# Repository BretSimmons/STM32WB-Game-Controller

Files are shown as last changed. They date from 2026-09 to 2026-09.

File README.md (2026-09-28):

# STM32WB Game Controller

Custom microcontroller for running embedded games and other programming projects.

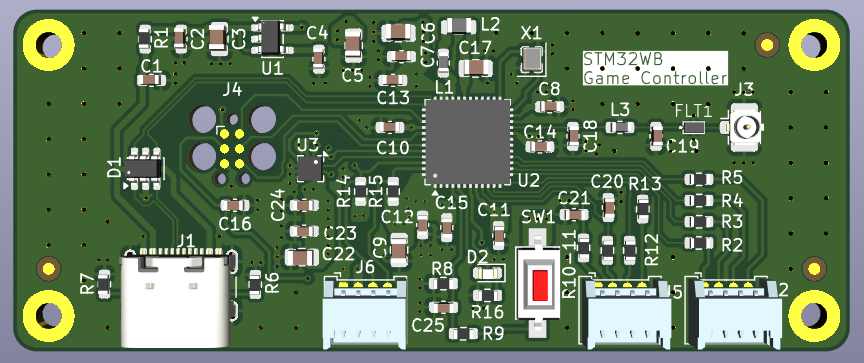
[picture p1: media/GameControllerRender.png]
Demo


**Functionality:**

My original idea for this board was to create a microcontroller to run an embedded pong game I wrote a few months ago [(here)](https://github.com/BretSimmons/Embedded-Pong). I ended up adding the requried perhipherals (I2C, ADC, and 4 GPIO pins), but also UART, and a connector for an RF antenna. I wanted to create a multi purpose microcontroller I can use in future projects, and gain experience impedence matching traces for high frequencies.

**How It Works:**

The board is powered by an USB-C header and runs through ESD protection and a step down voltage regulator to power the STM32WB55xx MCU. The MCU can be programmed via either the USB or a Tag Connect header. The MCU contains several internal clocks, and I additionally included an external crystal oscillator. The perhipherals can be configured via software, and routed out via the Molex headers on the board. 

**Future Updates:**

This project is a work in progress, and there are still a couple of changes I want to make before ordering the PCB. Once I have it ordered and assembled I will update this repo with a video demo.

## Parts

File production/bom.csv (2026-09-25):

Designator | Footprint | Quantity | Value | LCSC Part #
C1, C10, C11, C12, C13, C14, C15, C16, C2, C20, C21, C23, C24, C25, C4, C7, C8 | 0603 | 17 | 100n
C17, C22, C3, C5, C6, C9 | 0805 | 6 | 4u7
C18 | 0603 | 1 | 0p8
C19 | 0603 | 1 | 0p3
D1 | SOT-23-6 | 1 | USBLC6-2SC6
D2 | 0603 | 1 | LED
FLT1 | DLF162500LT-5028A1 | 1 | DLF162500LT-5028A1
J1 | USB_C_Receptacle_GCT_USB4105-xx-A_16P_TopMnt_Horizontal | 1 | USB_C_Receptacle_USB2.0_14P
J2, J5, J6 | Molex_PicoBlade_53048-0410_1x04_P1.25mm_Horizontal | 3 | Conn_01x04_Pin
J3 | U.FL_Hirose_U.FL-R-SMT-1_Vertical | 1 | Conn_Coaxial
L1 | 0603 | 1 | 10n
L2 | 0805 | 1 | 10u
L3 | 0603 | 1 | 2n7
R1 | 0603 | 1 | 0R
R10-11, R11, R14, R15, R6, R7, R8 | 0603 | 7 | 5k1
R12, R13, R16, R2, R3, R4, R5, R9 | 0603 | 8 | 220R
SW1 | SW_SPST_CK_RS282G05A3 | 1 | SW_Push
U1 | SOT-23-5 | 1 | SPX3819M5-L-3-3
U2 | QFN-48-1EP_7x7mm_P0.5mm_EP5.6x5.6mm | 1 | STM32WB55CEU6
U3 | LGA-12_2x2mm_P0.5mm | 1 | LIS2HH12
X1 | Crystal_SMD_2016-4Pin_2.0x1.6mm | 1 | 32MHz

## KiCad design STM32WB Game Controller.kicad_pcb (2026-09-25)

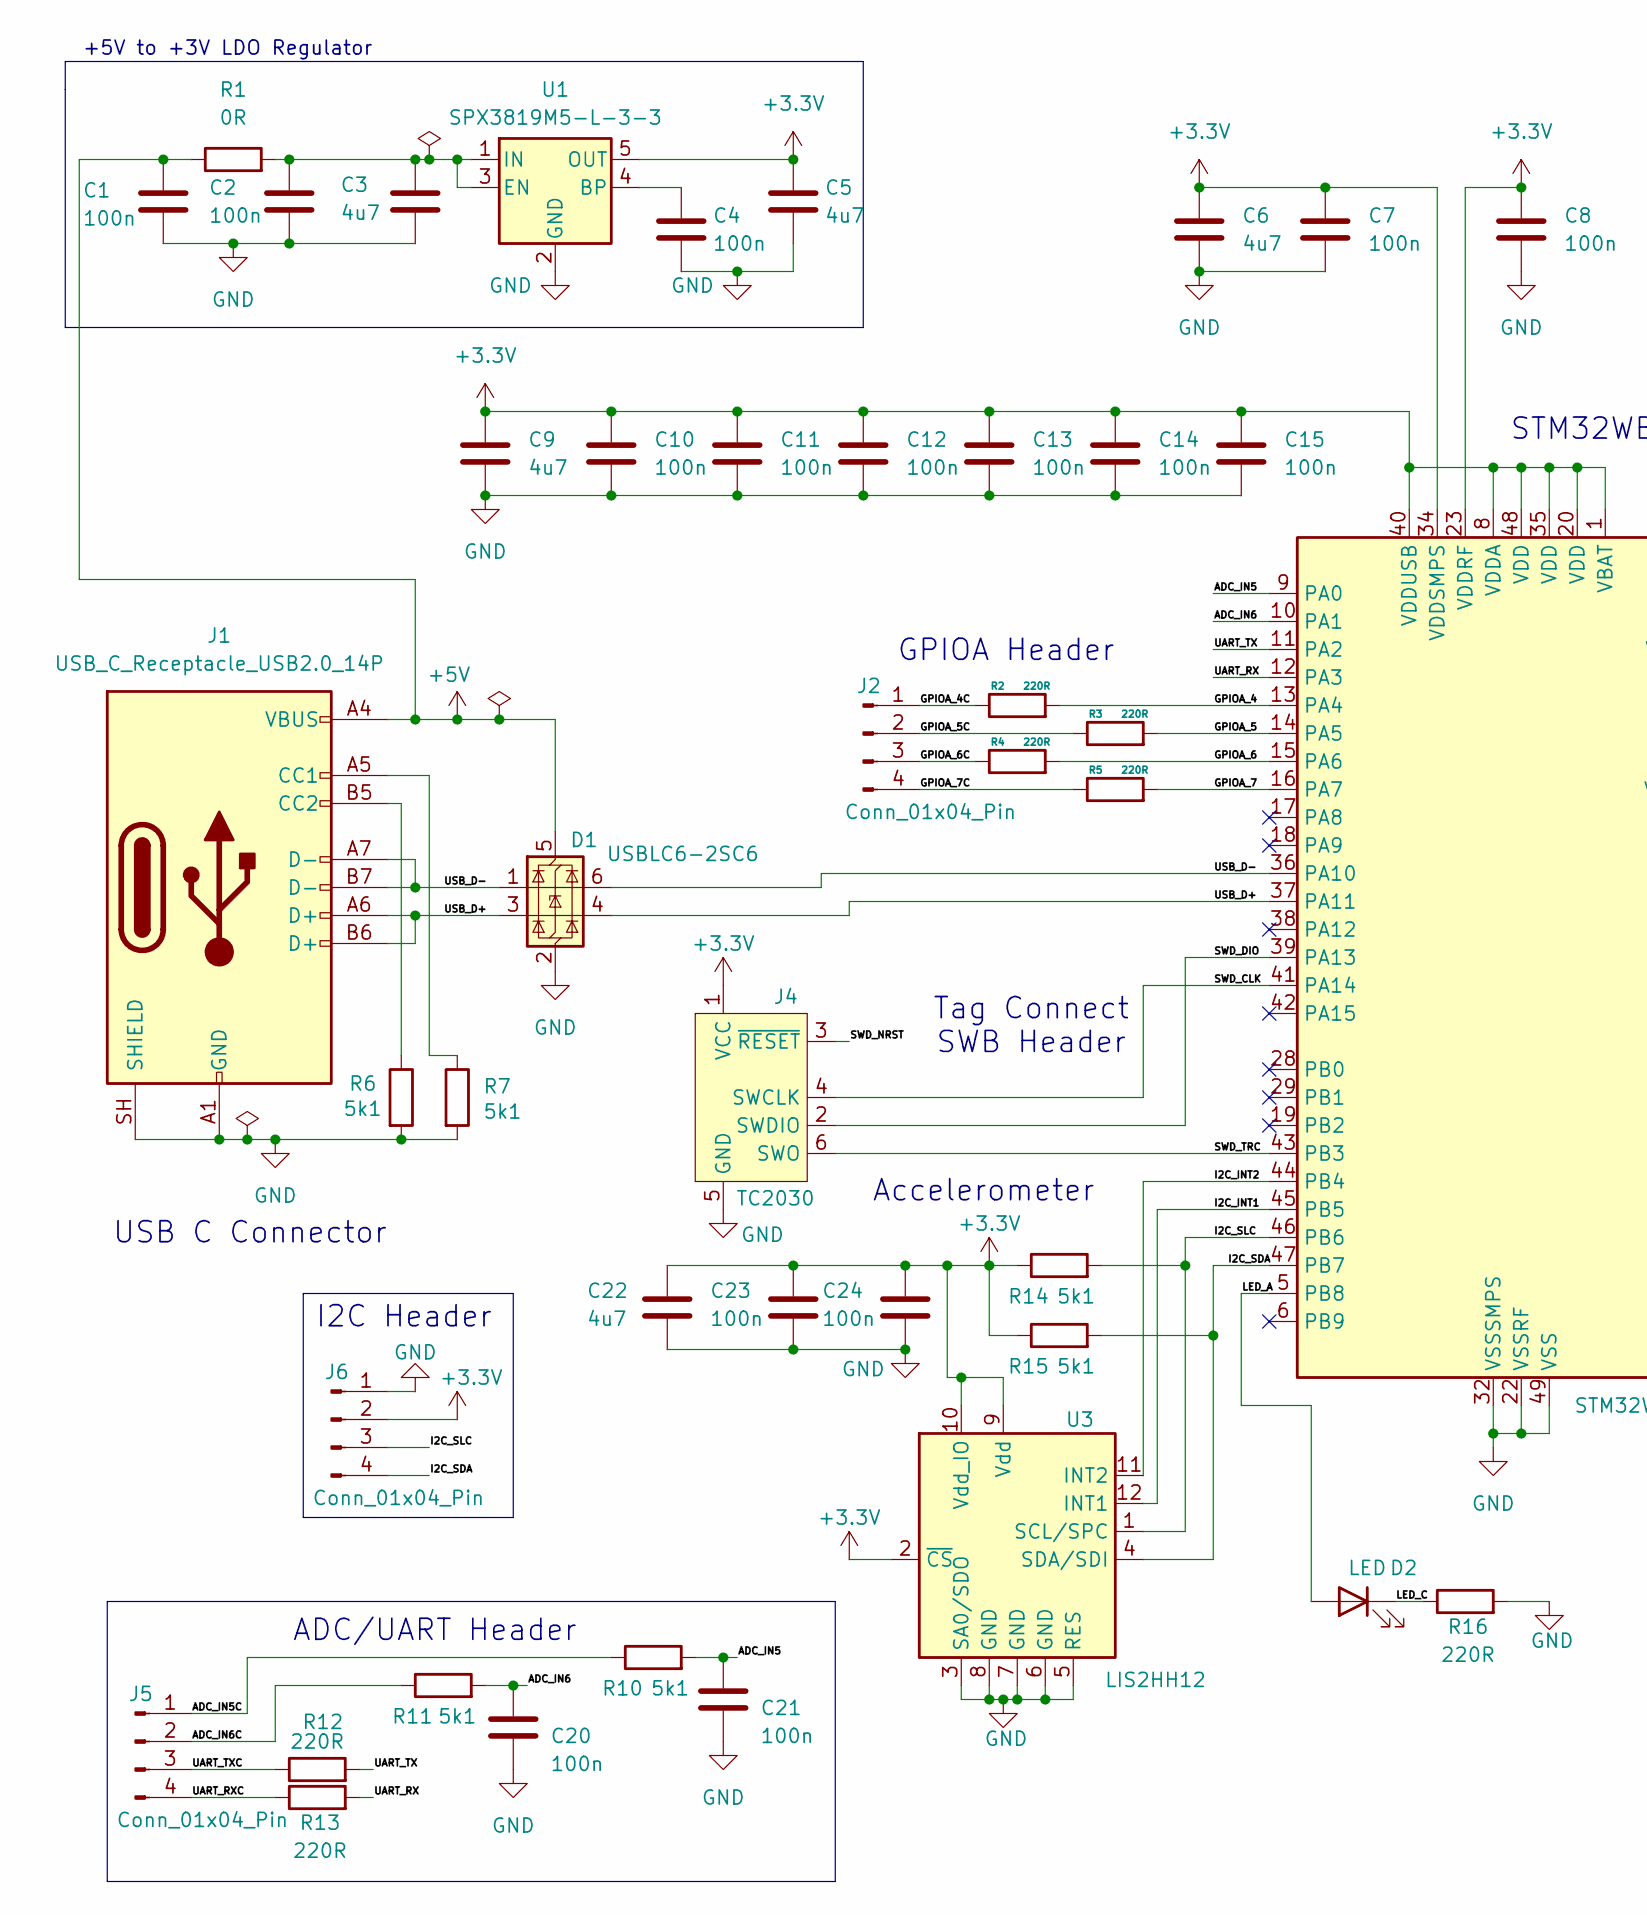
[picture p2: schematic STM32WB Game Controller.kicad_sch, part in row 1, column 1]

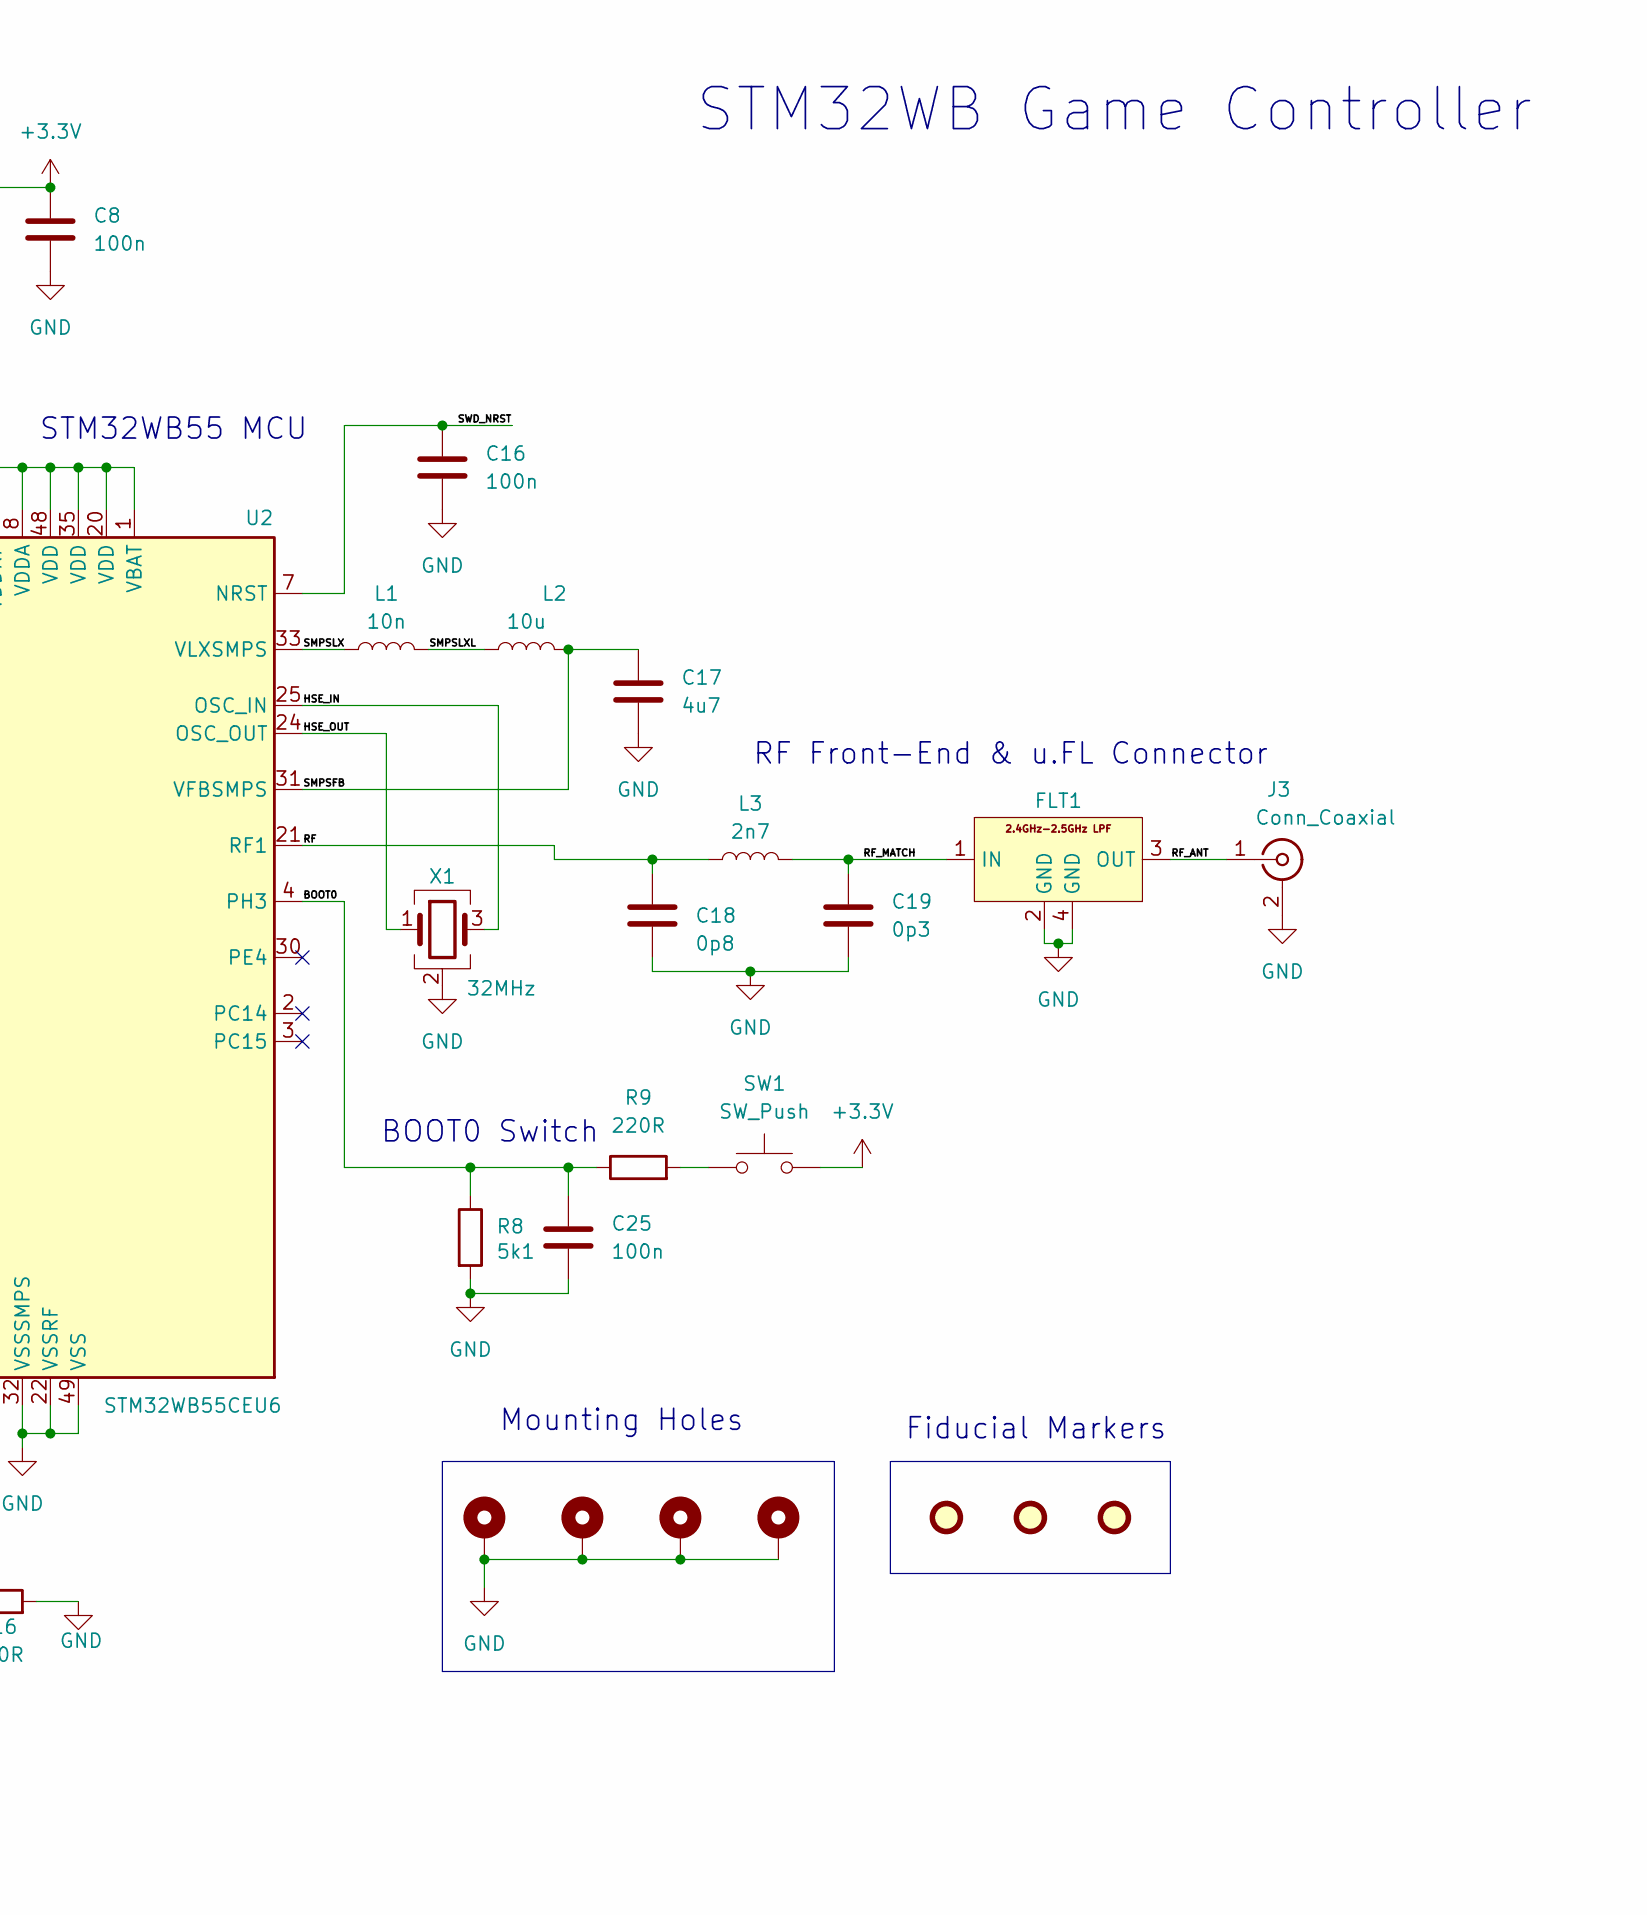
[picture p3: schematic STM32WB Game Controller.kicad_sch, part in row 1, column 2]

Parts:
C1, C2, C4, C7, C8, C10, C11, C12, C13, C14, C15, C16, C20, C21, C23, C24, C25: 100n; C_0603_1608Metric; Manufacturer Part Number CC0603JRX7R9BB104
C3, C5, C6, C9, C17, C22: 4u7; C_0805_2012Metric; Manufacturer Part Number CL21A475KPFNNNE
C18: 0p8; C_0603_1608Metric; Manufacturer Part Number CC0603BRNPO9BNR80
C19: 0p3; C_0603_1608Metric; Manufacturer Part Number 0603N0R3C500CT
D1: USBLC6-2SC6; SOT-23-6; Manufacturer Part Number USBLC6-2SC6
D2: LED; LED_0603_1608Metric; Manufacturer Part Number KT EELP41.12-S2U1-25-2X4X-5-R18
FID1, FID2, FID3: Fiducial; Fiducial_1mm_Mask2mm
FLT1: DLF162500LT-5028A1; Manufacturer Part Number DLF162500LT-5028A1
H1, H2, H3, H4: MountingHole_Pad; MountingHole_2.2mm_M2_Pad
J1: USB_C_Receptacle_USB2.0_14P; USB_C_Receptacle_GCT_USB4105-xx-A_16P_TopMnt_Horizontal; Manufacturer Part Number USB4105-GF-A
J2, J5, J6: Conn_01x04_Pin; Molex_PicoBlade_53048-0410_1x04_P1.25mm_Horizontal; Manufacturer Part Number 53048-0410
J3: Conn_Coaxial; U.FL_Hirose_U.FL-R-SMT-1_Vertical; Manufacturer Part Number U.FL-R-SMT(01)
J4: TC2030; Tag-Connect_TC2030-IDC-FP_2x03_P1.27mm_Vertical
L1: 10n; L_0603_1608Metric; Manufacturer Part Number LCCI0603J10NGTAR
L2: 10u; L_0805_2012Metric; Manufacturer Part Number MLZ2012M100WT000
L3: 2n7; L_0603_1608Metric; Manufacturer Part Number MCL1608V2-2R7-R
R1: 0R; R_0603_1608Metric; Manufacturer Part Number AF0603JR-130RL
R2, R3, R4, R5, R9, R12, R13, R16: 220R; R_0603_1608Metric; Manufacturer Part Number AF0603FR-07220RL
R6, R7, R8, R10, R11, R14, R15: 5k1; R_0603_1608Metric; Manufacturer Part Number RC0603FR-105K1L
SW1: SW_Push; SW_SPST_CK_RS282G05A3; Manufacturer Part Number RS-282G05A3-SM RT
U1: SPX3819M5-L-3-3; SOT-23-5; Manufacturer Part Number SPX3819M5-L-3-3/TR
U2: STM32WB55CEU6; QFN-48-1EP_7x7mm_P0.5mm_EP5.6x5.6mm; Manufacturer Part Number STM32WB55CEU6
U3: LIS2HH12; LGA-12_2x2mm_P0.5mm; Manufacturer Part Number LIS2HH12TR
X1: 32MHz; Crystal_SMD_2016-4Pin_2.0x1.6mm; Manufacturer Part Number CX2016SA32000F0HPQG1

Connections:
+3.3V: C5.1, C6.1, C7.1, C8.1, C9.1, C10.1, C11.1, C12.1, C13.1, C14.1, C15.1, C22.1, C23.1, C24.1, J4.1 (VCC), J6.2, R14.1, R15.1, SW1.2, U1.5 (OUT), U2.1 (VBAT), U2.8 (VDDA), U2.20 (VDD), U2.23 (VDDRF), U2.34 (VDDSMPS), U2.35 (VDD), U2.40 (VDDUSB), U2.48 (VDD), U3.2 (~CS), U3.9 (Vdd), U3.10 (Vdd_IO)
+5V: C1.1, D1.5 (VBUS), J1.A4 (VBUS), J1.A9 (VBUS), J1.B4 (VBUS), J1.B9 (VBUS), R1.1
/ADC_IN5: C21.1, R10.2, U2.9 (PA0); also elsewhere on the board
/ADC_IN5C: J5.1, R10.1; also elsewhere on the board
/ADC_IN6: C20.1, R11.2, U2.10 (PA1)
/ADC_IN6C: J5.2, R11.1
/BOOT0: C25.1, R8.1, R9.1, U2.4 (PH3)
/GPIOA_4: R2.2, U2.13 (PA4)
/GPIOA_4C: J2.1, R2.1
/GPIOA_5: R3.2, U2.14 (PA5)
/GPIOA_5C: J2.2, R3.1
/GPIOA_6: R4.2, U2.15 (PA6)
/GPIOA_6C: J2.3, R4.1
/GPIOA_7: R5.2, U2.16 (PA7)
/GPIOA_7C: J2.4, R5.1
/HSE_IN: U2.25 (OSC_IN), X1.3
/HSE_OUT: U2.24 (OSC_OUT), X1.1
/I2C_INT1: U2.45 (PB5), U3.12 (INT1)
/I2C_INT2: U2.44 (PB4), U3.11 (INT2)
/I2C_SDA: J6.4, R15.2, U2.47 (PB7), U3.4 (SDA/SDI)
/I2C_SLC: J6.3, R14.2, U2.46 (PB6), U3.1 (SCL/SPC)
/LED_A: D2.2 (A), U2.5 (PB8)
/LED_C: D2.1 (K), R16.1
/RF: C18.1, L3.1, U2.21 (RF1)
/RF_ANT: FLT1.3 (OUT), J3.1 (In)
/RF_MATCH: C19.1, FLT1.1 (IN), L3.2
/SMPSFB: C17.1, L2.2, U2.31 (VFBSMPS)
/SMPSLX: L1.1, U2.33 (VLXSMPS)
/SMPSLXL: L1.2, L2.1
/SWD_CLK: J4.4 (SWCLK), U2.41 (PA14)
/SWD_DIO: J4.2 (SWDIO), U2.39 (PA13)
/SWD_NRST: C16.1, J4.3 (~RESET), U2.7 (NRST)
/SWD_TRC: J4.6 (SWO), U2.43 (PB3)
/UART_RX: R13.2, U2.12 (PA3)
/UART_RXC: J5.4, R13.1
/UART_TX: R12.2, U2.11 (PA2)
/UART_TXC: J5.3, R12.1
/USB_D+: D1.3 (I/O2), D1.4 (I/O2), J1.A6 (D+), J1.B6 (D+), U2.37 (PA11)
/USB_D-: D1.1 (I/O1), D1.6 (I/O1), J1.A7 (D-), J1.B7 (D-), U2.36 (PA10)
GND: C1.2, C2.2, C3.2, C4.2, C5.2, C6.2, C7.2, C8.2, C9.2, C10.2, C11.2, C12.2, C13.2, C14.2, C15.2, C16.2, C17.2, C18.2, C19.2, C20.2, C21.2, C22.2, C23.2, C24.2, C25.2, D1.2 (GND), FLT1.2 (GND), FLT1.4 (GND), H1.1 (1_1), H2.1 (1_1), H3.1 (1_1), H4.1 (1_1), J1.A1 (GND), J1.A12 (GND), J1.B1 (GND), J1.B12 (GND), J1.SH (SHIELD), J3.2 (Ext), J4.5 (GND), J6.1, R6.2, R7.2, R8.2, R16.2, U1.2 (GND), U2.22 (VSSRF), U2.32 (VSSSMPS), U2.49 (VSS), U3.3 (SA0/SDO), U3.5 (RES), U3.6 (GND), U3.7 (GND), U3.8 (GND), X1.2 (G), X1.4 (G)
unnamed: J1.A5 (CC1), R7.1
unnamed: J1.B5 (CC2), R6.1
unnamed: R9.2, SW1.1
unnamed: C4.1, U1.4 (BP)
unnamed: C2.1, C3.1, R1.2, U1.1 (IN), U1.3 (EN)

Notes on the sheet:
RF Front-End & u.FL Connector
BOOT0 Switch
Accelerometer
ADC/UART Header
Mounting Holes
Tag Connect SWB Header
GPIOA Header
STM32WB Game Controller
STM32WB55 MCU
+5V to +3V LDO Regulator
I2C Header
Fiducial Markers
USB C Connector

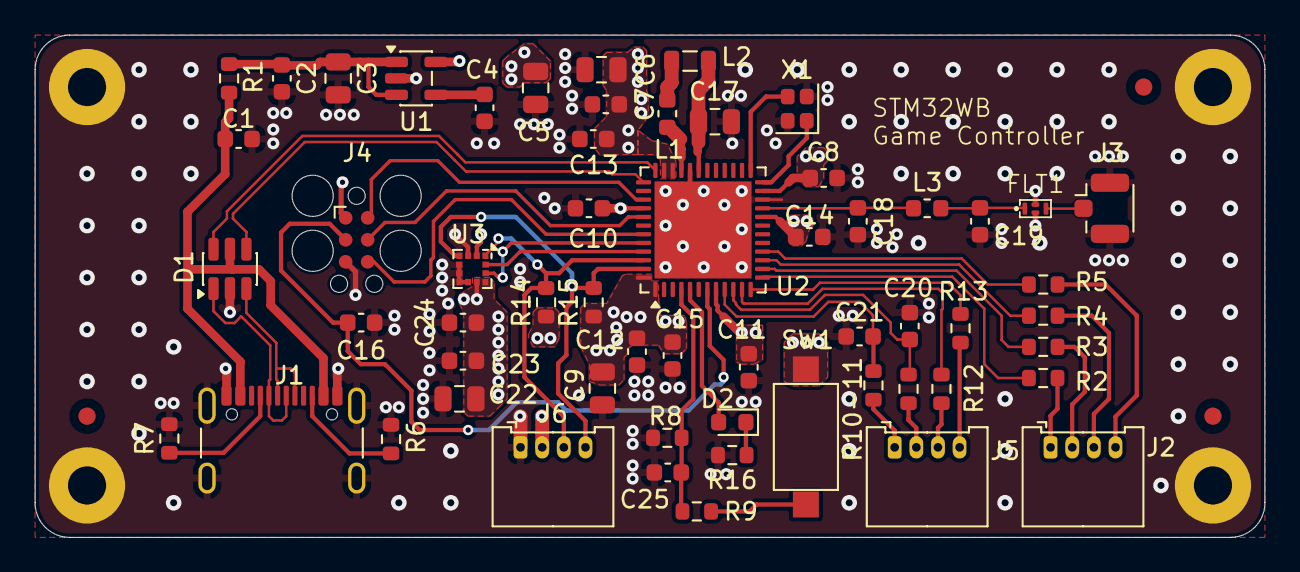
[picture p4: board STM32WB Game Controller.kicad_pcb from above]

Board: 4 copper layers, 71.0 x 29.0 mm, 65 parts (0 on the bottom side), 45 nets.

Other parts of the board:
R10-11: 5k1; R_0603_1608Metric

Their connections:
/ADC_IN5: R10-11.2; also elsewhere on the board
/ADC_IN5C: R10-11.1; also elsewhere on the board

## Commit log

2026-09-25 Finished layout and routing
    [STM32WB Game Controller.kicad_pcb, STM32WB Game Controller.kicad_sch, bom.csv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]
2026-10-20 Cleaned up schematic and redid vias on pcb
